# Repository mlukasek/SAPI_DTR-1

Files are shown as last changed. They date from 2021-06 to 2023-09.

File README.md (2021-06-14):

# SAPI-1 DTR-1 (Deska Testeru a RAM)

DTR-1 je modení deska pro starší 8-bitový počítač SAPI-1. Jedná se o poměrně univerzální desku, která může sloužit pro různé funkce podle nainstalovaného firmware. V současnosti firmware umožňuje:
- rychle (cca 2 min) nahrát obsah RAM disku ZRMD-1 z nebo do PC přes USB (za chodu SAPI i bez dalších desek ve sběrnici)
- nahradit desku DMR-1, resp. na ní obsažených DSM-1 a RAM-1Z (handshaking není zatím implementován)
- otestovat video RAM v AND-1Z/89
- otestovat základní RAM počítače

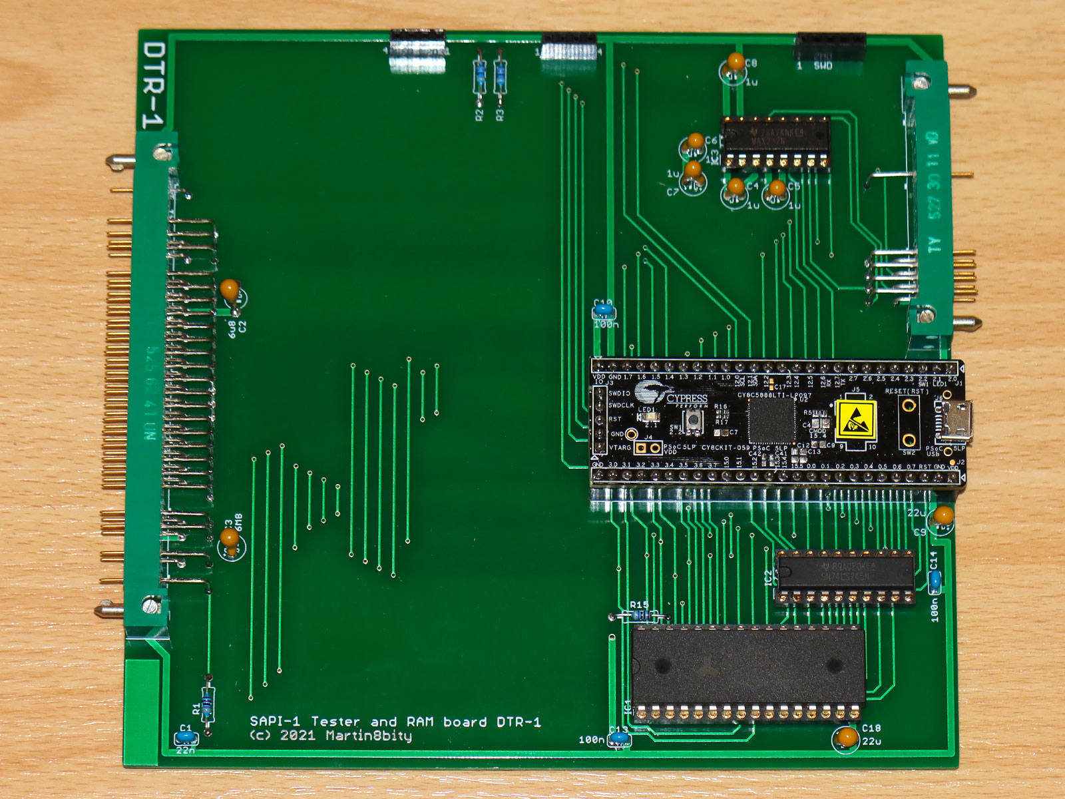
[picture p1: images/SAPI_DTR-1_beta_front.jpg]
DTR-1 PCB photo


Deska DTR-1 využívá levný Cypress (Infineon) kit CY8CKIT-059 pro různé funkce. Základem kitu je PSoC (Programmable System on a Chip) CY8C5888LTI-LP097, který kromě procesor ARM Cortex-M3 obsahuje i propojovatelnou digitální a analogovou část (něco jako CPLD). Z kitu je potřeba odpájet některé součástky, které jinak zamezují funkci některých vývodů, jakožto standardních GPIO pinů a v podstatě tak kit funguje jen jako breakout z SMD na THT technologii, aby nebylo nutné pájet SMD pouzdro.

[Schéma zapojení](https://github.com/mlukasek/SAPI_DTR-1/blob/main/HW/DTR-1_v2021-05-06_SCH.pdf)

[Seznam součástek](https://github.com/mlukasek/SAPI_DTR-1/blob/main/HW/DTR-1_v2021-05-06_BOM.csv)

[Gerber/Excellon pro výrobu DPS](https://github.com/mlukasek/SAPI_DTR-1/blob/main/HW/Gerber/DTR-1_v2021-05-06_Gerber_cor.zip)

## Odpájení některých součástek z CY8CKIT-059

Pro správnou funkci DTR-1 je potřeba z desky CY8CKIT-059 odstranit (odpájet) některé součástky. Kit je částečně analogový a na některých pinech jsou součástky, převážně kondenzátory, které by nám digitální komunikaci na sběrnici kazili, proto je potřeba asi 6 kondíků a jeden odpor z desky odpájet. Já to dělám tak, že na součástku přidám cín tak, abych byl schopen hrotem páječky z boku ohřát oba konce současně a pak součástku snadno oddělám a přebytečný cín odsaji lankem.

Konkrétně se jedná o následující součástky:
- C7, C9, C12, C13 - SAR bypass capacitors
- C41, C42 - 32 kHz crystal capacitors
- R5 nebo C4 - CMOD
- R18 - User LED resistor
- SW1 - User push button (možno ponechat, ale nesmí se stisknout, jinak připojí A2 natvrdo na GND)

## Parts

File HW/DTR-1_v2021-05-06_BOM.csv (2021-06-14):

Qty | Parts | Value | Device | Package | Description
1 | IC1 | SRAM 628128/628512 | TC551001CP | DIL32 | MEMORY SRAM
1 | IC2 | 74LS245 | 74LS245N | DIL20 | Octal BUS TRANSCEIVER 3-state
1 | IC3 | MAX232 | MAX232 | DIL16 | RS232 TRANSCEIVER
1 | Q1 | BS170 | BS170 | SOT54E | N-CHANNEL MOS FET
1 | D1 | 1N5817 | 1N5817-B | DO41-7.6 | 1.0A SCHOTTKY BARRIER RECTIFIER
1 | R1 | 47k | R-EU_0207/10 | 0207/10 | RESISTOR European symbol
3 | R2 R3 R15 | 4k7 | R-EU_0207/10 | 0207/10 | RESISTOR European symbol
1 | RN1 | DNI (optional data pull-up ~10k) | RN08 | RN-9 | RESISTOR NETWORK
1 | C1 | 22 nF | C-EU025-024X044 | C025-024X044 | CAPACITOR European symbol
3 | C10 C13 C14 | 100 nF | C-EU025-024X044 | C025-024X044 | CAPACITOR European symbol
1 | C11 | 100 nF | C-EU050-025X075 | C050-025X075 | CAPACITOR European symbol
1 | C2 | 6.8 uF | CPOL-EUE5-4 | E5-4 | POLARIZED CAPACITOR European symbol
1 | C3 | 6.8 uF | CPOL-EUE2.5-5 | E2.5-5 | POLARIZED CAPACITOR European symbol
5 | C4 C5 C6 C7 C8 | 1 uF | CPOL-EUE2.5-5 | E2.5-5 | POLARIZED CAPACITOR European symbol
2 | C9 C18 | 22 uF | CPOL-EUE2.5-5 | E2.5-5 | POLARIZED CAPACITOR European symbol
2 | JP1 JP2 | OLED power select jumper | 1x3 pin header | JP2 | JUMPER
2 | JP3 JP4 | INT/OLED jumper | 1x3 pin header | JP2 | JUMPER
1 | JP5 | optional serial module power | 1x2 pin header | 1X02 | PIN HEADER
1 | S1 | RESET | 31-XX | B3F-31XX | OMRON SWITCH
1 | SV1 | SWD | 1x5 female header + 1x5 pin header | MA05-1 | PIN HEADER
1 | SV10 | optional serial module IO | 1x4 pin header | MA04-1 | PIN HEADER
2 | SV11 SV12 | optional logic analyser connector | 1x4 pin header | MA04-1 | PIN HEADER
2 | SV2 SV3 | OLED | MA04-1 | MA04-1 | PIN HEADER
3 | SV4 SV5 SV6 | optional logic analyser connector | 1x8 pin header | MA08-1 | PIN HEADER
1 | SV7 | optional logic analyser connector | 1x10 pin header | MA10-1 | PIN HEADER
2 | SV8 SV9 | optional logic analyser connector | 1x3 pin header | MA03-1 | PIN HEADER
1 | U$1 | CY8CKIT-059 | CY8CKIT-059
2 | U$1 | CY8CKIT-059 I/O pins | 1x28 female header + 1x28 pin header
1 | U$1 | CY8CKIT-059 SWD pins | 1x5 female header + 1x5 pin header
1 | X1 | SAPI bus | SAPI_DTR-1_X1_TY_MP | TY5176211
1 | X2 | RS-232c | SAPI_DMR-1_X2_TY_MP | TY5133011

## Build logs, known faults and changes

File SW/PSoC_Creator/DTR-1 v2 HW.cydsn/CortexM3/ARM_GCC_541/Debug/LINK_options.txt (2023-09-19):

-Wl,--start-group -o "C:\\Users\\Kiwi\\Documents\\PSoC\ Creator\\DTR-1\ v2\ HW.cydsn\\CortexM3\\ARM_GCC_541\\Debug\\DTR-1\ v2\ HW.elf" ".\\CortexM3\\ARM_GCC_541\\Debug\\main.o" ".\\CortexM3\\ARM_GCC_541\\Debug\\ssd1306.o" ".\\CortexM3\\ARM_GCC_541\\Debug\\cyfitter_cfg.o" ".\\CortexM3\\ARM_GCC_541\\Debug\\cymetadata.o" ".\\CortexM3\\ARM_GCC_541\\Debug\\Cm3Start.o" ".\\CortexM3\\ARM_GCC_541\\Debug\\DTR-1\ v2\ HW.a" "C:\\Program\ Files\ (x86)\\Cypress\\PSoC\ Creator\\4.4\\PSoC\ Creator\\psoc\\content\\cycomponentlibrary\\CyComponentLibrary.cylib\\CortexM3\\ARM_GCC_541\\Debug\\CyComponentLibrary.a" -mcpu=cortex-m3 -mthumb -L "Generated_Source\\PSoC5" "-Wl,-Map,.\\CortexM3\\ARM_GCC_541\\Debug/DTR-1\ v2\ HW.map" -T "Generated_Source\\PSoC5\\cm3gcc.ld" -specs=nano.specs -Wl,--gc-sections -g -ffunction-sections -Og -ffat-lto-objects -Wl,--end-group

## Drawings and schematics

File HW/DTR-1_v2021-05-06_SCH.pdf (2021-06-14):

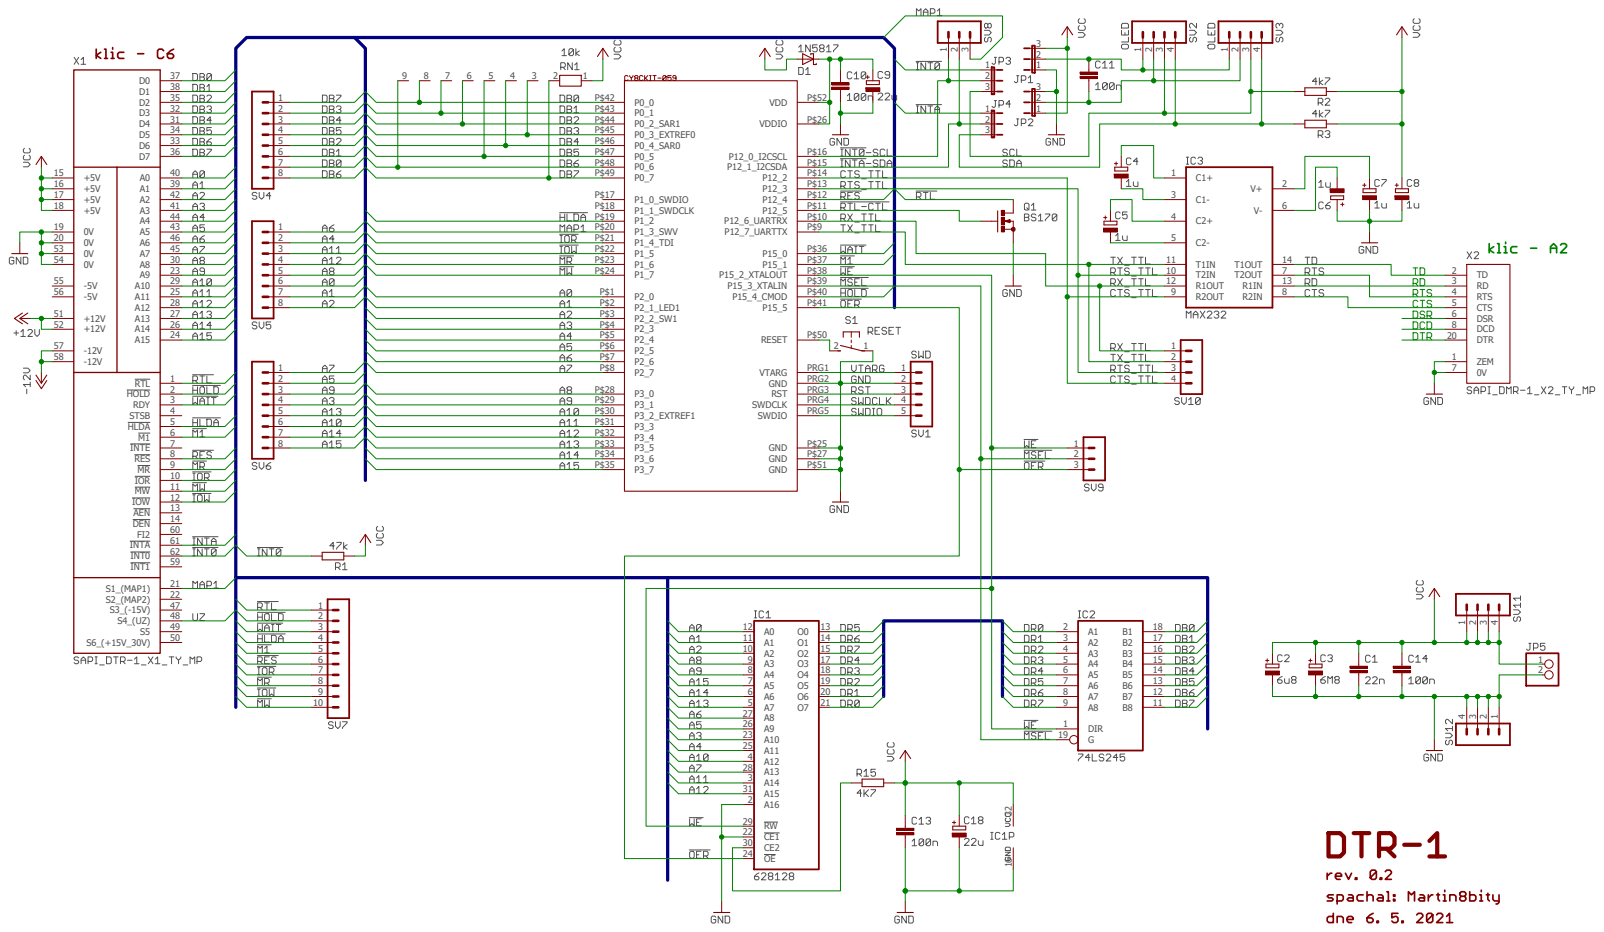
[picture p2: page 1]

+12V 52 | P2_3 P$4
-12V 57 -12V 58 | P2_4 P$5

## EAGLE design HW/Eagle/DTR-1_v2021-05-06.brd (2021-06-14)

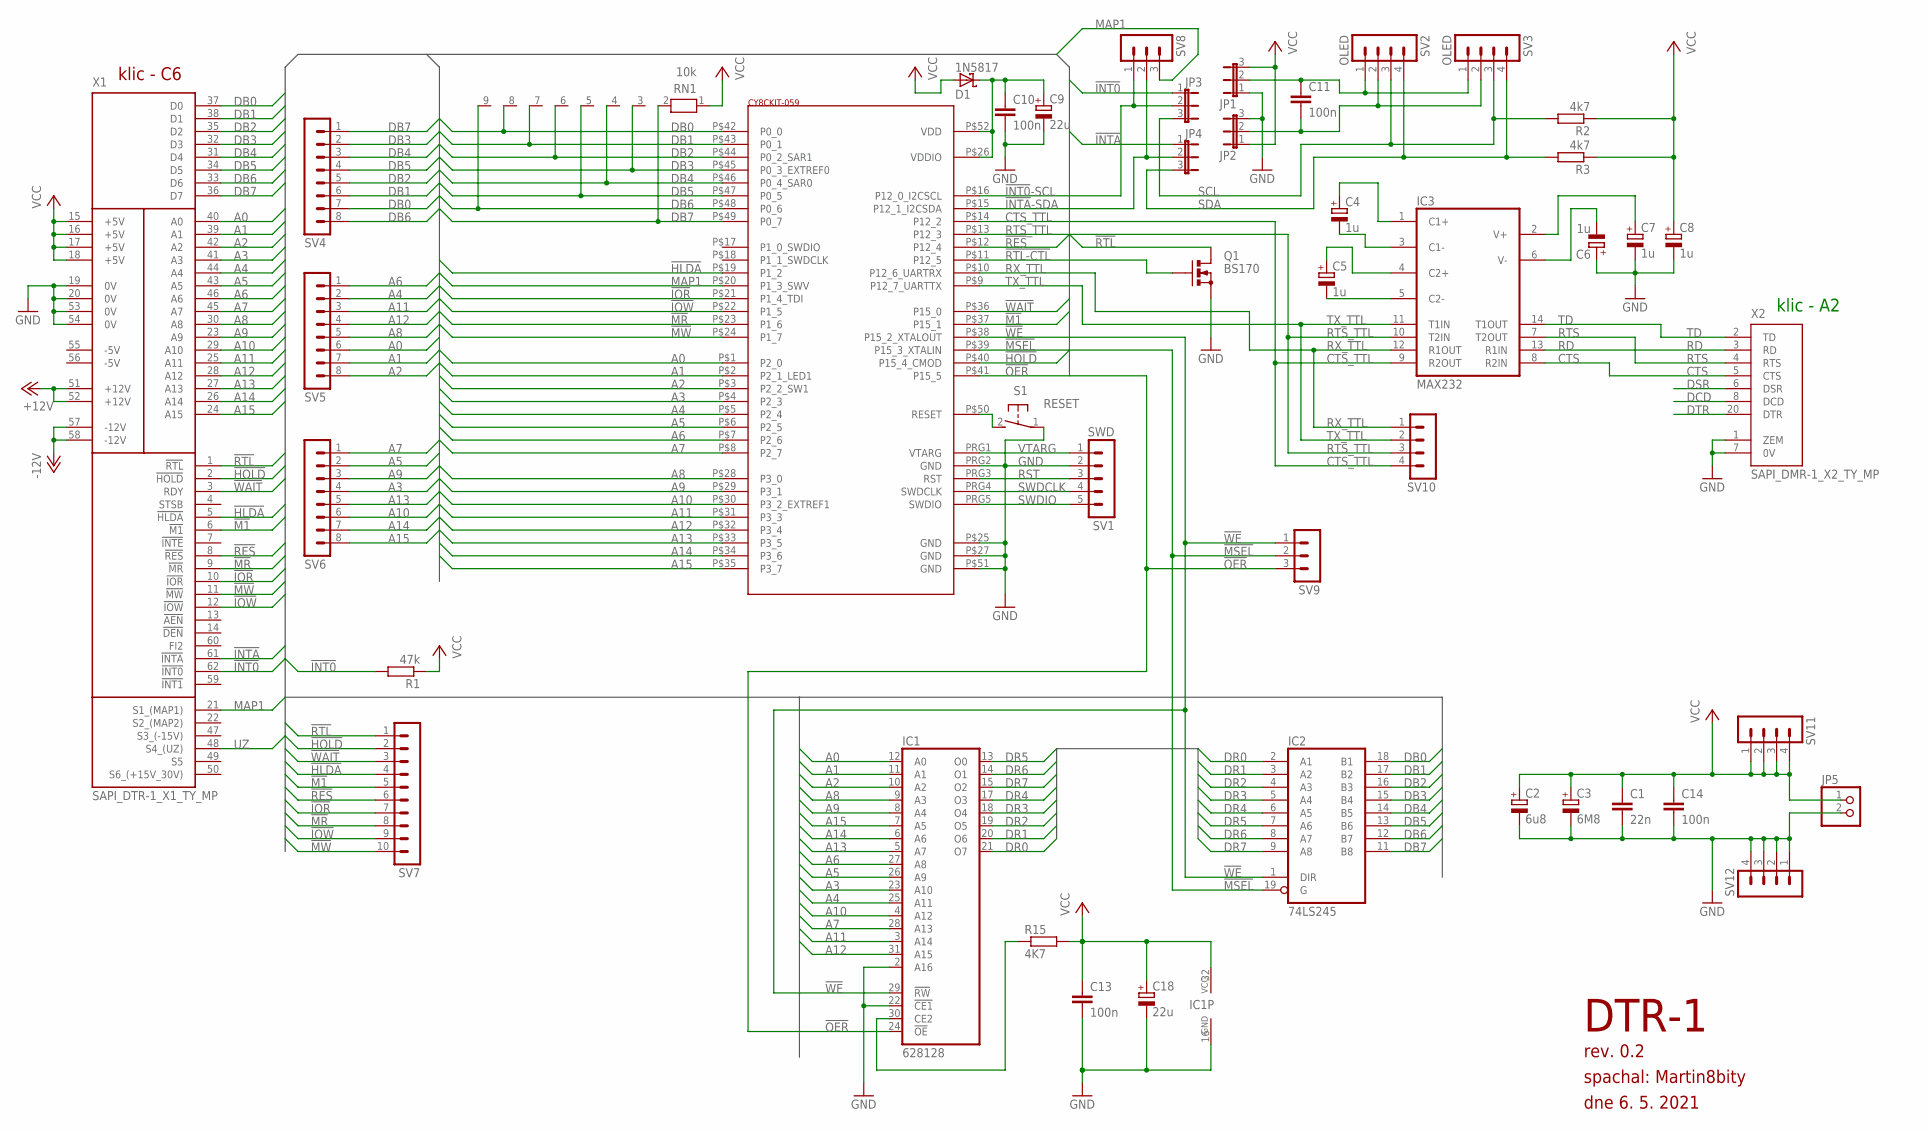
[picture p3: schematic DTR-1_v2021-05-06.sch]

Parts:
C1: 22n; C025-024X044
C2: 6u8; E5-4
C3: 6M8; E2,5-5
C4, C5, C6, C7, C8: 1u; E2,5-5
C9, C18: 22u; E2,5-5
C10, C13, C14: 100n; C025-024X044
C11: 100n; C050-025X075
D1: 1N5817; DO41-7.6
IC1: 628128; DIL32
IC2: 74LS245; DIL20
IC3: MAX232; DIL16
JP1, JP2, JP3, JP4: JP2E; JP2
JP5: PINHD-1X2; 1X02
Q1: BS170; SOT54E
R1: 47k; 0207/10
R2, R3: 4k7; 0207/10
R15: 4K7; 0207/10
RN1: 10k; RN-9
S1: RESET; B3F-31XX
SV1: SWD; MA05-1
SV2, SV3: OLED; MA04-1
SV4, SV5, SV6: MA08-1
SV7: MA10-1
SV8, SV9: MA03-1
SV10, SV11, SV12: MA04-1
U$1: CY8CKIT-059; PSOC-KIT-26
X1: SAPI_DTR-1_X1_TY_MP; TY5176211/DTR-1_X1
X2: SAPI_DMR-1_X2_TY_MP; TY5133011/DMR-1_X2

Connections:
!HLDA: SV7.4, U$1.P$19 (P1_2), X1.5 (!HLDA)
!HOLD: SV7.2, U$1.P$40 (P15_4_CMOD), X1.2 (!HOLD)
!INT0: JP3.1, R1.2, X1.62 (!INT0)
!INT0!-SCL: JP3.2, SV8.1, U$1.P$16 (P12_0_I2CSCL)
!INTA: JP4.1, X1.61 (!INTA)
!INTA!-SDA: JP4.2, SV8.2, U$1.P$15 (P12_1_I2CSDA)
!IOR: SV7.7, U$1.P$21 (P1_4_TDI), X1.10 (!IOR)
!IOW: SV7.9, U$1.P$22 (P1_5), X1.12 (!IOW)
!M1: SV7.5, U$1.P$37 (P15_1), X1.6 (!M1)
!MR: SV7.8, U$1.P$23 (P1_6), X1.9 (!MR)
!MSEL: IC2.19 (G), SV9.2, U$1.P$39 (P15_3_XTALIN)
!MW: SV7.10, U$1.P$24 (P1_7), X1.11 (!MW)
!OER: IC1.24 (!OE), SV9.3, U$1.P$41 (P15_5)
!RES: SV7.6, U$1.P$12 (P12_4), X1.8 (!RES)
!RTL: Q1.D, SV7.1, X1.1 (!RTL)
!RTL-CTL: Q1.G, U$1.P$11 (P12_5)
!WAIT: SV7.3, U$1.P$36 (P15_0), X1.3 (RDY)
!WE: IC1.29 (!RW), IC2.1 (DIR), SV9.1, U$1.P$38 (P15_2_XTALOUT)
+12V: X1.51 (+12V), X1.52 (+12V)
-12V: X1.57 (-12V), X1.58 (-12V)
A0: IC1.12 (A0), SV5.6, U$1.P$1 (P2_0), X1.40 (A0)
A1: IC1.11 (A1), SV5.7, U$1.P$2 (P2_1_LED1), X1.39 (A1)
A2: IC1.10 (A2), SV5.8, U$1.P$3 (P2_2_SW1), X1.42 (A2)
A3: IC1.23 (A10), SV6.4, U$1.P$4 (P2_3), X1.41 (A3)
A4: IC1.25 (A11), SV5.2, U$1.P$5 (P2_4), X1.44 (A4)
A5: IC1.26 (A9), SV6.2, U$1.P$6 (P2_5), X1.43 (A5)
A6: IC1.27 (A8), SV5.1, U$1.P$7 (P2_6), X1.46 (A6)
A7: IC1.28 (A13), SV6.1, U$1.P$8 (P2_7), X1.45 (A7)
A8: IC1.9 (A3), SV5.5, U$1.P$28 (P3_0), X1.30 (A8)
A9: IC1.8 (A4), SV6.3, U$1.P$29 (P3_1), X1.23 (A9)
A10: IC1.4 (A12), SV6.6, U$1.P$30 (P3_2_EXTREF1), X1.29 (A10)
A11: IC1.3 (A14), SV5.3, U$1.P$31 (P3_3), X1.25 (A11)
A12: IC1.31 (A15), SV5.4, U$1.P$32 (P3_4), X1.28 (A12)
A13: IC1.5 (A7), SV6.5, U$1.P$33 (P3_5), X1.27 (A13)
A14: IC1.6 (A6), SV6.7, U$1.P$34 (P3_6), X1.26 (A14)
A15: IC1.7 (A5), SV6.8, U$1.P$35 (P3_7), X1.24 (A15)
CTS: IC3.8 (R2IN), X2.5 (CTS)
CTS_TTL: IC3.9 (R2OUT), SV10.4, U$1.P$14 (P12_2)
DB0: IC2.18 (B1), RN1.8, SV4.7, U$1.P$42 (P0_0), X1.37 (D0)
DB1: IC2.17 (B2), RN1.7, SV4.6, U$1.P$43 (P0_1), X1.38 (D1)
DB2: IC2.16 (B3), RN1.6, SV4.5, U$1.P$44 (P0_2_SAR1), X1.35 (D2)
DB3: IC2.15 (B4), RN1.3, SV4.2, U$1.P$45 (P0_3_EXTREF0), X1.32 (D3)
DB4: IC2.14 (B5), RN1.4, SV4.3, U$1.P$46 (P0_4_SAR0), X1.31 (D4)
DB5: IC2.13 (B6), RN1.5, SV4.4, U$1.P$47 (P0_5), X1.34 (D5)
DB6: IC2.12 (B7), RN1.9, SV4.8, U$1.P$48 (P0_6), X1.33 (D6)
DB7: IC2.11 (B8), RN1.2, SV4.1, U$1.P$49 (P0_7), X1.36 (D7)
DCD: X2.8 (DCD)
DR0: IC1.21 (O7), IC2.2 (A1)
DR1: IC1.20 (O6), IC2.3 (A2)
DR2: IC1.19 (O5), IC2.4 (A3)
DR3: IC1.18 (O4), IC2.5 (A4)
DR4: IC1.17 (O3), IC2.6 (A5)
DR5: IC1.13 (O0), IC2.7 (A6)
DR6: IC1.14 (O1), IC2.8 (A7)
DR7: IC1.15 (O2), IC2.9 (A8)
DSR: X2.6 (DSR)
DTR: X2.20 (DTR)
GND: C1.2, C2.-, C3.-, C6.+, C7.-, C8.-, C9.-, C10.2, C13.2, C14.2, C18.-, IC1.2 (A16), IC1.16 (GND), IC1.22 (!CE1), IC2.10 (GND), IC3.15 (GND), JP1.1, JP2.3, JP5.2, Q1.S, S1.1, SV1.2, SV12.1, SV12.2, SV12.3, SV12.4, U$1.P$25 (GND), U$1.P$27 (GND), U$1.P$51 (GND), U$1.PRG2 (GND), X1.19 (0V), X1.20 (0V), X1.53 (0V), X1.54 (0V), X2.1 (ZEM), X2.7 (0V)
MAP1: SV8.3, U$1.P$20 (P1_3_SWV), X1.21 (S1_(MAP1))
unnamed: C9.+, C10.1, D1.C, U$1.P$26 (VDDIO), U$1.P$52 (VDD)
unnamed: S1.2 (S), U$1.P$50 (RESET)
unnamed: C11.1, JP1.2, SV2.1, SV3.1
unnamed: C6.-, IC3.6 (V-)
unnamed: C7.+, IC3.2 (V+)
unnamed: C5.-, IC3.5 (C2-)
unnamed: C5.+, IC3.4 (C2+)
unnamed: C4.-, IC3.3 (C1-)
unnamed: C4.+, IC3.1 (C1+)
unnamed: C11.2, JP2.2, SV2.2, SV3.2
unnamed: IC1.30 (CE2), R15.1
RD: IC3.13 (R1IN), X2.3 (RD)
RST: SV1.3, U$1.PRG3 (RST)
RTS: IC3.7 (T2OUT), X2.4 (RTS)
RTS_TTL: IC3.10 (T2IN), SV10.3, U$1.P$13 (P12_3)
RX_TTL: IC3.12 (R1OUT), SV10.1, U$1.P$10 (P12_6_UARTRX)
SCL: JP3.3, R2.2, SV2.3, SV3.3
SDA: JP4.3, R3.2, SV2.4, SV3.4
SWDCLK: SV1.4, U$1.PRG4 (SWDCLK)
SWDIO: SV1.5, U$1.PRG5 (SWDIO)
TD: IC3.14 (T1OUT), X2.2 (TD)
TX_TTL: IC3.11 (T1IN), SV10.2, U$1.P$9 (P12_7_UARTTX)
UZ: X1.48 (S4_(UZ))
VCC: C1.1, C2.+, C3.+, C8.+, C13.1, C14.1, C18.+, D1.A, IC1.32 (VCC), IC2.20 (VCC), IC3.16 (VCC), JP1.3, JP2.1, JP5.1, R1.1, R2.1, R3.1, R15.2, RN1.1, SV11.1, SV11.2, SV11.3, SV11.4, X1.15 (+5V), X1.16 (+5V), X1.17 (+5V), X1.18 (+5V)
VTARG: SV1.1, U$1.PRG1 (VTARG)

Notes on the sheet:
DTR-1
spachal: Martin8bity
dne 6. 5. 2021
klic - C6
klic - A2
rev. 0.2

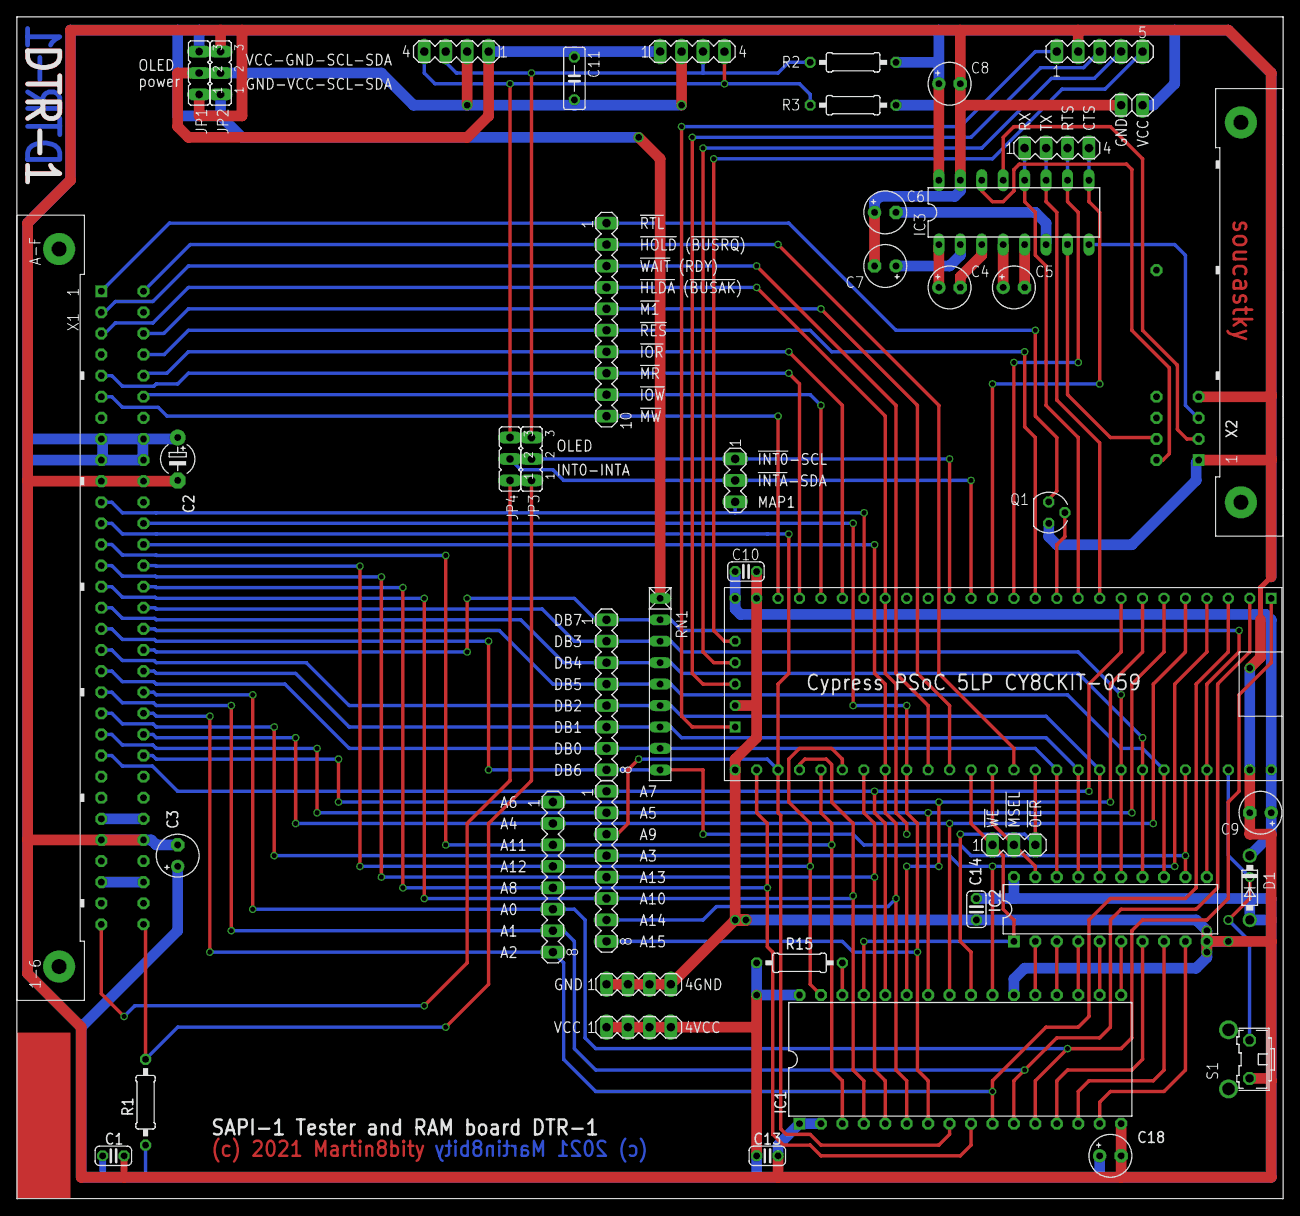
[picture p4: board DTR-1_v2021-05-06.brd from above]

Board: 2 copper layers, 150.0 x 140.0 mm, 45 parts (0 on the bottom side), 80 nets.

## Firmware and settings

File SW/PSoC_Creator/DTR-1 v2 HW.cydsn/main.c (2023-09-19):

/* ========================================
 *
 * Copyright Martin Lukasek (c) 2021
 * All Rights Reserved
 * UNPUBLISHED, LICENSED SOFTWARE.
 *
 * CONFIDENTIAL AND PROPRIETARY INFORMATION
 * WHICH IS THE PROPERTY OF Martin Lukasek.
 *
 * ========================================
*/
#include <stdio.h>
#include <stdarg.h>
#include "project.h"
#include "ssd1306.h"

#define DISPLAY_ADDRESS 0x3C // 011110+SA0+RW - 0x3C or 0x3D

int noUART = 1;
uint16 extaddr = 0;
uint32 cntTime = 0;
uint32 cntLines = 0;
uint32 cntErrs = 0;
uint8 waitForBus = 1;

int noOLED = 1;

struct PortData
{
    uint8 port;
    uint8 data;
};

struct PortData intQueue[256];
volatile uint8 intCnt = 0;
volatile uint8 rdCnt = 0;

struct InstData
{
    uint16 addr;
    uint8 data;
};

struct InstData instQueue[256];
volatile uint8 instCnt = 0;
volatile uint8 instRdCnt = 0;

CY_ISR( UART_OUT_RCM_Handler )
{
    intQueue[intCnt].port = 0x10;
    intQueue[intCnt].data = RCM_Read();
    intCnt++;
}

CY_ISR( UART_OUT_RCU_Handler )
{
    intQueue[intCnt].port = 0x11;
    intQueue[intCnt].data = RCU_Read();
    intCnt++;
}

CY_ISR( UART_OUT_ROD_Handler )
{
    intQueue[intCnt].port = 0x12;
    intQueue[intCnt].data = ROD_Read();
    intCnt++;
}

CY_ISR( UART_OUT_RST_Handler )
{
    intQueue[intCnt].port = 0x13;
    intQueue[intCnt].data = RST_Read();
    intCnt++;
}

CY_ISR( UART_IN_RRD_Handler )
{
    RSU_Write( RSU_Read() & 0x7F );
}

CY_ISR( M1_Int_Handler )
{
    nWAIT_Write(0);
    //instQueue[instCnt].addr = (AddrH_Read()<<8) + AddrL_Read();
    //instQueue[instCnt].data = Dta_Read();
    //CyDelay(2);
    instQueue[instCnt].addr = (ADH_Reg_Read()<<8) + ADL_Reg_Read();
    instQueue[instCnt].data = DT_Reg_Read();
    instCnt++;
}

#define BS170
void SAPI_Reset() {
#ifdef BS170
    RTL_Write(1);
    CyDelay(6);
    RTL_Write(0);
#else
    RTL_Write(0);
    CyDelay(6);
    RTL_Write(1);
#endif
    //CyDelay(1);
}

int USBUART_printf(const char *format, ...)
{
    if(noUART)
        return -1;

    char tmpstr[128];
    int ret;
    
    va_list args;
    va_start(args, format);

    ret=vsprintf(tmpstr, format, args);
    while(!USBUART_CDCIsReady());
    USBUART_PutString(tmpstr);
    
    va_end(args);
    
    return ret;
}    

int UART_printf(const char *format, ...)
{
    char tmpstr[128];
    int ret;
    
    va_list args;
    va_start(args, format);

    ret=vsprintf(tmpstr, format, args);
    // while(!UART_CDCIsReady());
    UART_PutString(tmpstr);
    
    va_end(args);
    
    return ret;
}    

/*
void TermPutString(char * str) {
    if(noUART)
        return;
    if(strlen(str)>50) // aaa - correct later, but large string would block
        return;
    uint32 timeout = Millis_ReadCounter();
    if (0u != USBUART_GetConfiguration()) {    
        while (0u == USBUART_CDCIsReady())
        {
            if (Millis_ReadCounter()-timeout > 100) {
                return; // prevent getting stuck
            }
        }    
        USBUART_PutString(str);
    }
    timeout = Millis_ReadCounter();
    while((!USBUART_CDCIsReady()) && (Millis_ReadCounter()-timeout<100)){     // Wait for Tx to finish, timeout after 100 ms
        CyDelay(1);
    }
}    

void TermPutChar(char ch) {
    if(noUART)
        return;
    // USBUART_PutChar(ch);
    uint32 timeout = Millis_ReadCounter();
    if (0u != USBUART_GetConfiguration()) {    
        while (0u == USBUART_CDCIsReady())
        {
            if (Millis_ReadCounter()-timeout > 100) {
                return; // prevent getting stuck
            }
        }    
        USBUART_PutChar(ch);
    }
    timeout = Millis_ReadCounter();
    while((!USBUART_CDCIsReady()) && (Millis_ReadCounter()-timeout<100)){     // Wait for Tx to finish, timeout after 100 ms
        CyDelay(1);
    }
}    
*/

uint8 Get_SAPI_Bus() {
    // USBUART_printf("BUSAK = %d\r\n", BUSAK_Read());
    if(waitForBus==0)
        return 1;
    BUSRQ_Write(0);
    USBUART_printf("Waiting BUSAK ... ");
    while(BUSAK_Read()!=0) {
        USBUART_printf(".");
        CyDelay(10);
    }
    if(BUSAK_Read()==0) {
        USBUART_printf("OK\r\n");
        return 1;
    } else {
        USBUART_printf("FAILED\r\n");
        return 0;
    }
}

uint8 Get_SAPI_Bus_Silent() {
    // USBUART_printf("BUSAK = %d\r\n", BUSAK_Read());
    if(waitForBus==0)
        return 1;
    BUSRQ_Write(0);
    //USBUART_printf("Waiting BUSAK ... ");
    while(BUSAK_Read()!=0) {
        //USBUART_printf(".");
        CyDelay(1);
    }
    if(BUSAK_Read()==0) {
        //USBUART_printf("OK\r\n");
        return 1;
    } else {
        //USBUART_printf("FAILED\r\n");
        return 0;
    }
}

uint8 Release_SAPI_Bus() {
    if(waitForBus==0)
        return 1;
    BUSRQ_Write(1);
    USBUART_printf("Waiting BUS release ... ");
    while(BUSAK_Read()!=1) {
        USBUART_printf(".");
        CyDelay(10);
    }
    if(BUSAK_Read()==1) {
        USBUART_printf("OK\r\n");
        return 1;
    } else {
        USBUART_printf("FAILED\r\n");
        return 0;
    }
}

uint8 Release_SAPI_Bus_Silent() {
    if(waitForBus==0)
        return 1;
    BUSRQ_Write(1);
    //USBUART_printf("Waiting BUS release ... ");
    while(BUSAK_Read()!=1) {
        //USBUART_printf(".");
        CyDelay(1);
    }
    if(BUSAK_Read()==1) {
        //USBUART_printf("OK\r\n");
        return 1;
    } else {
        //USBUART_printf("FAILED\r\n");
        return 0;
    }
}

void DumpMem(uint16 addr);

void RAM_check() {
    uint32 testfrom = 0x0000;
    uint32 testlen = 0x10000;
    uint8 r;
    uint8 s;
    int err=0;
    
    if(!Get_SAPI_Bus()) {
        return;
    }

    AddrL_Write(0);
    AddrL_SetDriveMode(PIN_DM_STRONG);
    AddrH_Write(0);
    AddrH_SetDriveMode(PIN_DM_STRONG);
    
    // SRAM under my control DATAOUT CTL OER WE MSEL
    SRAM_Ctl_Write(0b01111);
    
    USBUART_printf("filling RAM with patttern\r\n");
    for(uint32 a=testfrom; a<testfrom+testlen; a=a+2) {
        AddrH_Write((a>>8)&0xFF);
        AddrL_Write(a&0xFF);
        BusDta_Write((a>>8)&0xFF);
        // DATAOUT + WE + MSEL
        SRAM_Ctl_Write(0b11100);
        CyDelayUs(1);
        SRAM_Ctl_Write(0b01111);
        CyDelayUs(1);
        AddrL_Write((a&0xFF)+1);
        BusDta_Write(a);
        SRAM_Ctl_Write(0b11100);
        CyDelayUs(1);
        SRAM_Ctl_Write(0b01111);
        CyDelayUs(1);
    }
    USBUART_printf("verifying RAM\r\n");

    // OER + MSEL = furt data ze SRAM na sbernici
    SRAM_Ctl_Write(0b01010);

    for(uint32 a=testfrom; a<testlen; a++) {
        AddrH_Write((a>>8)&0xFF);
        AddrL_Write(a&0xFF);
        CyDelayUs(2);
        r=Dta_Read();
        CyDelayUs(1);
        //USBUART_printf("%02X", r);
        //if((a&0x1F)==0x1F)
        //    USBUART_printf("\r\n");
        if(a&1) {
            s=(a&0xFF)-1;
        } else {
            s=(a>>8)&0xFF;
        }
        if(r!=s) {
            USBUART_printf("Error at %04X, expected %02X, but found %02X\r\n", a, s, r);
            err++;
            DumpMem(a & 0xFF00);
            if(!Get_SAPI_Bus()) {
                return;
            }
            AddrL_SetDriveMode(PIN_DM_STRONG);
            AddrH_SetDriveMode(PIN_DM_STRONG);
            SRAM_Ctl_Write(0b01010);
        }
    }

    // SRAM under my control DATAOUT CTL OER WE MSEL
    SRAM_Ctl_Write(0b01111);
    
    USBUART_printf("filling RAM with inverted patttern\r\n");
    for(uint32 a=testfrom; a<testfrom+testlen; a=a+2) {
        AddrH_Write((a>>8)&0xFF);
        AddrL_Write(a&0xFF);
        BusDta_Write(~((a>>8)&0xFF));
        // DATAOUT + WE + MSEL
        SRAM_Ctl_Write(0b11100);
        CyDelayUs(1);
        SRAM_Ctl_Write(0b01111);
        CyDelayUs(1);
        AddrL_Write((a&0xFF)+1);
        BusDta_Write(~a);
        SRAM_Ctl_Write(0b11100);
        CyDelayUs(1);
        SRAM_Ctl_Write(0b01111);
        CyDelayUs(1);
    }
    USBUART_printf("verifying RAM\r\n");

    // OER + MSEL = furt data ze SRAM na sbernici
    SRAM_Ctl_Write(0b01010);

    for(uint32 a=testfrom; a<testlen; a++) {
        AddrH_Write((a>>8)&0xFF);
        AddrL_Write(a&0xFF);
        CyDelayUs(1);
        r=Dta_Read();
        CyDelayUs(1);
        //USBUART_printf("%02X", r);
        //if((a&0x1F)==0x1F)
        //    USBUART_printf("\r\n");
        if(a&1) {
            s=~((a&0xFF)-1);
        } else {
            s=~((a>>8)&0xFF);
        }
        if(r!=s) {
            USBUART_printf("Error at %04X, expected %02X, but found %02X\r\n", a, s, r);
            err++;
        }
    }

    // relase SRAM to SAPI - CTL OER WE MSEL
    SRAM_Ctl_Write(0b00111);
    
    AddrL_Write(0);
    AddrL_SetDriveMode(PIN_DM_DIG_HIZ);
    AddrH_Write(0);
    AddrH_SetDriveMode(PIN_DM_DIG_HIZ);
    //Dta_Write(0xFF);
    //Dta_SetDriveMode(PIN_DM_RES_UP);
    
    if(err) {
        USBUART_printf("%d errors found :-(\r\n", err);
    } else {
        USBUART_printf("No errors found :-)\r\n");
    }
    Release_SAPI_Bus();

    USBUART_printf("Data has been corrupted by memory test, performing SAPI reset.\r\n");
    SAPI_Reset();
}

void DumpMem(uint16 addr) {
    uint8 r;

    if(!Get_SAPI_Bus()) {
        return;
    }

    // SRAM under my control DATAOUT CTL OER WE MSEL
    SRAM_Ctl_Write(0b01111);
    
    AddrL_Write(0);
    AddrL_SetDriveMode(PIN_DM_STRONG);
    AddrH_Write(0);
    AddrH_SetDriveMode(PIN_DM_STRONG);
    
    // USBUART_printf("reading RAM\r\n");

    // OER + MSEL = furt SRAM data na sbernici
    SRAM_Ctl_Write(0b01010);

    for(uint32 a=addr; a<addr+256; a++) {
        AddrH_Write((a>>8)&0xFF);
        AddrL_Write(a&0xFF);
        CyDelayUs(5);
        r=Dta_Read();
        CyDelayUs(5);
        if((a&0x1F)==0x00)
            USBUART_printf("%04X: ", a);
        USBUART_printf("%02X", r);
        if((a&0x1F)==0x1F)
            USBUART_printf("\r\n");
    }

    // relase SRAM to SAPI - DATAOUT CTL OER WE MSEL
    SRAM_Ctl_Write(0b00111);
    
    AddrL_Write(0);
    AddrL_SetDriveMode(PIN_DM_DIG_HIZ);
    AddrH_Write(0);
    AddrH_SetDriveMode(PIN_DM_DIG_HIZ);
    
    Release_SAPI_Bus();
}

void TestVideo() {
    uint8 r;
    uint16 err=0;

    if(!Get_SAPI_Bus()) {
        return;
    }

    AddrL_Write(0);
    AddrL_SetDriveMode(PIN_DM_STRONG);
    AddrH_Write(0);
    AddrH_SetDriveMode(PIN_DM_STRONG);
    MW_Write(1);
    MW_SetDriveMode(PIN_DM_STRONG);
    MR_Write(1);
    MR_SetDriveMode(PIN_DM_STRONG);
    
    USBUART_printf("Checking AND-1Z video RAM 0xF800-0xFCFF\r\n");

    /*
    for(uint32 a=0xF000; a<0xF000+256; a++) {
        AddrH_Write((a>>8)&0xFF);
        AddrL_Write(a&0xFF);
        MR_Write(0);
        CyDelayUs(5);
        r=Dta_Read();
        CyDelayUs(5);
        if((a&0x1F)==0x00)
            USBUART_printf("%04X: ", a);
        USBUART_printf("%02X", r);
        if((a&0x1F)==0x1F)
            USBUART_printf("\r\n");
    }
    */
    for(uint32 a=0xF800; a<0xF800+1280; a++) {
        AddrH_Write((a>>8)&0xFF);
        AddrL_Write(a&0xFF);
        // read current value
        MR_Write(0);
        CyDelayUs(5);
        r=Dta_Read();
        MR_Write(1);
        CyDelayUs(5);
        
        // write 0xA5
        BusDta_Write(0xA5);
        // BusData to bus (DATAOUT CTL OER WE MSEL)
        SRAM_Ctl_Write(0b10111);
        MW_Write(0);
        CyDelayUs(5);
        MW_Write(1);
        SRAM_Ctl_Write(0b00111);
        CyDelayUs(5);
        // check 0xA5
        MR_Write(0);
        CyDelayUs(5);
        if(Dta_Read()!=0xA5) {
            USBUART_printf("Error at %04X, expected %02X, found %02X\r\n", a, 0xA5, Dta_Read());
            err++;
        }
        MR_Write(1);
        CyDelayUs(5);
        
        // write 0x5A
        BusDta_Write(0x5A);
        // BusData to bus (DATAOUT CTL OER WE MSEL)
        SRAM_Ctl_Write(0b10111);
        MW_Write(0);
        CyDelayUs(5);
        MW_Write(1);
        SRAM_Ctl_Write(0b00111);
        CyDelayUs(5);
        // check 0x5A
        MR_Write(0);
        CyDelayUs(5);
        if(Dta_Read()!=0x5A) {
            USBUART_printf("Error at %04X, expected %02X, found %02X\r\n", a, 0x5A, Dta_Read());
            err++;
        }
        MR_Write(1);
        CyDelayUs(5);

        CyDelay(1);
        
        // write back original value
        BusDta_Write(r);
        // BusData to bus (DATAOUT CTL OER WE MSEL)
        SRAM_Ctl_Write(0b10111);
        MW_Write(0);
        CyDelayUs(5);
        MW_Write(1);
        SRAM_Ctl_Write(0b00111);
        CyDelayUs(5);
    }
    
    SRAM_Ctl_Write(0b00111);
    AddrL_Write(0);
    AddrL_SetDriveMode(PIN_DM_DIG_HIZ);
    AddrH_Write(0);
    AddrH_SetDriveMode(PIN_DM_DIG_HIZ);
    MR_Write(1);
    MR_SetDriveMode(PIN_DM_DIG_HIZ);
    MW_Write(1);
    MW_SetDriveMode(PIN_DM_DIG_HIZ);
    
    if(err==0) {
        USBUART_printf("No erros found :-)\r\n", err);
    } else {
        USBUART_printf("Found %d errors :-(\r\n", err);
    }
    
    Release_SAPI_Bus();
}

void WriteIO8(uint8 port, uint8 value) {
    // do not call this without reserving bus first
    AddrL_Write(port);
    BusDta_Write(value);
    SRAM_Ctl_Write(0b10111);
    //CyDelayUs(5);
    IOW_Write(0);
    CyDelayUs(4);
    IOW_Write(1);
    SRAM_Ctl_Write(0b00111);
    //CyDelayUs(5);
}
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
int main(void)
{
    CyGlobalIntEnable; /* Enable global interrupts. */
    
    RCM_Int_StartEx( UART_OUT_RCM_Handler );
    RCU_Int_StartEx( UART_OUT_RCU_Handler );
    ROD_Int_StartEx( UART_OUT_ROD_Handler );
    RST_Int_StartEx( UART_OUT_RST_Handler );
    RRD_Int_StartEx( UART_IN_RRD_Handler );
    M1_Int_StartEx( M1_Int_Handler );
    M1_Int_Disable();
    
    /* Place your initialization/startup code here (e.g. MyInst_Start()) */

    //AddrL_Write(0);
    
    Millis_Start();
    I2COLED_Start();
    UART_Start();
    // uint8 oledStatus = I2COLED_MasterStatus();
    // UART_printf("I2COLED_MasterStatus() = %02X\r\n", oledStatus);
    if(I2COLED_MasterSendStart(DISPLAY_ADDRESS, 0)) {
        I2COLED_MasterSendStop();
        // UART_printf("OLED display NOT present on the bus\r\n");
        noOLED = 1;
    } else {
        I2COLED_MasterSendStop();
        // UART_printf("OLED display present in the bus\r\n");
        //uint8 iniseq[] = {0xA8, 0x3F, 0xD3, 0x00, 0x40, 0xA0, 0xC0, 0xDA, 0x02, 0x81, 0x7F, 0xA4, 0xA6, 0xD5, 0x80, 0x8D, 0x14, 0xAF};
        // I2COLED_MasterClearStatus();
        //I2COLED_MasterWriteBuf(DISPLAY_ADDRESS, &iniseq, 18, 0 ); //I2C_MODE_COMPLETE_XFER
        //CyDelay(1000);
        noOLED = 0;
        display_init(DISPLAY_ADDRESS);
        display_clear();    
        gfx_setTextSize(2);
        gfx_setTextColor(WHITE);
        gfx_setTextBg(BLACK);
        gfx_setCursor(0,0);
        gfx_println("SAPI DTR-1");
        gfx_println("8bity.cz");
        gfx_println("2021042501");
        display_update();
    }

    cntTime = Millis_ReadCounter();
    
    USBUART_Start(0, USBUART_5V_OPERATION); //!!NOTE!! Make sure this matches your board voltage!
    uint32 timeout = Millis_ReadCounter();
    while((!USBUART_GetConfiguration()) && (Millis_ReadCounter()-timeout<2000)){
        CyDelay(1);
    }
    if(Millis_ReadCounter()-timeout<2000) {
        USBUART_CDC_Init();
        noUART = 0;
        /*gfx_setCursor(0,32);
        gfx_print("Ready     ");
        gfx_print("          ");
        display_update();*/
    } else {
        noUART = 1;
        /*gfx_setCursor(0,32);
        gfx_print("No USBUART");
        gfx_print("          ");
        display_update();*/
    }
    USBUART_printf("");
    USBUART_printf("\r\nSAPI-1 DTR-1 board based on CY8CKIT-059 rev.231709");
    USBUART_printf("  (c) 2021-23 martin@8bity.cz\r\n\r\n");

    //USBUART_printf("CTS = %d\r\n", CTS_Read());
    if( CTS_Read()==1 ) {
        RSM_Write(0x20);
        USBUART_printf("Console set to AND-1Z and Consul 262.3/259.11\r\n");
    } else {
        RSM_Write(0x00);
        USBUART_printf("Console set to RS-232c RTS/CTS flow control\r\n");
        UART_printf("\r\nHello to UART RS-232c console\r\n");
    }
    
    if(noOLED) {
        USBUART_printf("OLED display not found.\r\n");
    } else {
        USBUART_printf("OLED display detected.\r\n");
    }
    instCnt=0;
    instRdCnt=0;
    nWAIT_Write(1);
    //CyDelay(2);
    SAPI_Reset();
    int getInst=0;
    int tron=0;
    M1_Int_ClearPending();
    // M1_Int_Enable();
    
    
    char cmdline[128];
    uint8 inbuf[64];
    cmdline[0] = 0;
    char ch;
    // char tmpstr[256];
    int len;
    uint8 noPrompt = 0;

    USBUART_printf("DTR>");
    for(;;)
    {
        // process DSM-1 Register interrupt queue
        if(rdCnt!=intCnt) {
            // USBUART_printf("\r\nProcessing %d OUT interrupts:\r\n", intCnt-rdCnt);
            while(rdCnt!=intCnt) {
                // USBUART_printf("OUT: port=%d data=%d\r\n", intQueue[rdCnt].port, intQueue[rdCnt].data);
                // uint8 intStatus = CyEnterCriticalSection();
                switch(intQueue[rdCnt].port) {
                    case 0x10: // RCM
                        break;
                    case 0x11: // RCU
                        break;
                    case 0x12: // ROD
                        UART_PutChar(intQueue[rdCnt].data);
                        break;
                    case 0x13: // RST
                        break;
                }
                rdCnt++;
                //CyExitCriticalSection(intStatus);
            }
        }

        // process Instruction (M1) interrupt queue
        if(instRdCnt!=instCnt) {
            if(getInst>0) {
                USBUART_printf("TR %04X:%02X\r\n", instQueue[instRdCnt].addr, instQueue[instRdCnt].data);
                getInst--;
                if(getInst==0) {
                    M1_Int_Disable();
                    M1_Int_ClearPending();
                    tron=0;
                    USBUART_printf("DTR>");
                    noPrompt = 0;
                }
            }
            //USBUART_printf("%02X ", instQueue[instRdCnt].data);
            instRdCnt++;
            if(instRdCnt==instCnt)
                nWAIT_Write(1);
        }
        
        if(UART_GetRxBufferSize()>0) {
            RRD_Write( UART_GetByte() & 0x00FF );
            RSU_Write( RSU_Read() | 0x80 );
        }
        // process USBUART - command line
        if(USBUART_DataIsReady()>0) {
            int dtalen = USBUART_GetAll(inbuf);
            for(int i=0; i<dtalen; i++) {
                ch = inbuf[i];
                switch(ch) {
                  case 0x08: // backpasce
                    len = strlen(cmdline);
                    if(len>0) {
                        cmdline[len-1] = 0;
                        USBUART_printf("\b \b");            
                    }
                    break;
                  case 0x0D: // Enter
                    // USBUART_printf("\r\nWill process: [%s]\r\n", cmdline);
                    USBUART_printf("\r\n");
                    int cmdprocessed = 0;
                    if(cmdline[0]==':' && !cmdprocessed) {
                        ProcessHEX(cmdline);
                        cmdprocessed = 1;
                        noPrompt = 0;
                    }
                    if((strncmp(cmdline, "help", 4)==0 || strcmp(cmdline, "?")==0 || strcmp(cmdline, "h")==0) && !cmdprocessed) {
                        ShowHelp();
                        cmdprocessed = 1;
                        noPrompt = 0;
                    }
                    if(strcmp(cmdline, "zdump")==0 && !cmdprocessed) {
                        DumpZRMD();
                        cmdprocessed = 1;
                        noPrompt = 0;
                    }
                    if(strcmp(cmdline, "dumpu")==0 && !cmdprocessed) {
                        // DumpZRMD_UART();
                        cmdprocessed = 1;
                        noPrompt = 0;
                    }
                    if(strcmp(cmdline, "dm")==0 && !cmdprocessed) {
                        DumpMem(0xF000);
                        cmdprocessed = 1;
                        noPrompt = 0;
                    }
                    if(strcmp(cmdline, "vidtest")==0 && !cmdprocessed) {
                        TestVideo();
                        cmdprocessed = 1;
                        noPrompt = 0;
                    }
                    if(strcmp(cmdline, "hex")==0 && !cmdprocessed) {
                        HEX_read();
                        cmdprocessed = 1;
                        noPrompt = 0;
                    }
                    if(strcmp(cmdline, "memtest")==0 && !cmdprocessed) {
                        RAM_check();
                        cmdprocessed = 1;
                        noPrompt = 0;
                    }
                    if(strcmp(cmdline, "reset")==0 && !cmdprocessed) {
                        SAPI_Reset();
                        USBUART_printf("SAPI reset.\r\n", cmdline);
                        cmdprocessed = 1;
                        noPrompt = 0;
                    }
                    if(strcmp(cmdline, "rescnt")==0 && !cmdprocessed) {
                        cntTime = Millis_ReadCounter();
                        cntLines = 0;
                        cntErrs = 0;
                        USBUART_printf("Counter reset.\r\n", cmdline);
                        cmdprocessed = 1;
                        noPrompt = 0;
                    }
                    if(strcmp(cmdline, "cnt")==0 && !cmdprocessed) {
                        USBUART_printf("Elapsed time = %d ms, %d lines processed, %d errors\r\n", Millis_ReadCounter()-cntTime, cntLines, cntErrs);
                        cmdprocessed = 1;
                        noPrompt = 0;
                    }
                    if(strcmp(cmdline, "tron")==0 && !cmdprocessed) {
                        if(!tron) {
                            instCnt=0;
                            instRdCnt=0;
                            M1_Int_ClearPending();
                            M1_Int_Enable();
                            tron=1;
                        }
                        getInst=16;
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

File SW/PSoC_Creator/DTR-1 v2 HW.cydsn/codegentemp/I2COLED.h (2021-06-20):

/*******************************************************************************
* File Name: I2COLED.h
* Version 3.50
*
* Description:
*  This file provides constants and parameter values for the I2C component.

*
********************************************************************************
* Copyright 2008-2015, Cypress Semiconductor Corporation. All rights reserved.
* You may use this file only in accordance with the license, terms, conditions,
* disclaimers, and limitations in the end user license agreement accompanying
* the software package with which this file was provided.
*******************************************************************************/

#if !defined(CY_I2C_I2COLED_H)
#define CY_I2C_I2COLED_H

#include "cyfitter.h"
#include "cytypes.h"
#include "CyLib.h"

/* Check if required defines such as CY_PSOC5LP are available in cy_boot */
#if !defined (CY_PSOC5LP)
    #error Component I2C_v3_50 requires cy_boot v3.10 or later
#endif /* (CY_PSOC5LP) */


/***************************************
*   Conditional Compilation Parameters
****************************************/

#define I2COLED_IMPLEMENTATION     (1u)
#define I2COLED_MODE               (2u)
#define I2COLED_ENABLE_WAKEUP      (0u)
#define I2COLED_ADDR_DECODE        (1u)
#define I2COLED_UDB_INTRN_CLOCK    (0u)


/* I2C implementation enum */
#define I2COLED_UDB    (0x00u)
#define I2COLED_FF     (0x01u)

#define I2COLED_FF_IMPLEMENTED     (I2COLED_FF  == I2COLED_IMPLEMENTATION)
#define I2COLED_UDB_IMPLEMENTED    (I2COLED_UDB == I2COLED_IMPLEMENTATION)

#define I2COLED_UDB_INTRN_CLOCK_ENABLED    (I2COLED_UDB_IMPLEMENTED && \
                                                     (0u != I2COLED_UDB_INTRN_CLOCK))
/* I2C modes enum */
#define I2COLED_MODE_SLAVE                 (0x01u)
#define I2COLED_MODE_MASTER                (0x02u)
#define I2COLED_MODE_MULTI_MASTER          (0x06u)
#define I2COLED_MODE_MULTI_MASTER_SLAVE    (0x07u)
#define I2COLED_MODE_MULTI_MASTER_MASK     (0x04u)

#define I2COLED_MODE_SLAVE_ENABLED         (0u != (I2COLED_MODE_SLAVE  & I2COLED_MODE))
#define I2COLED_MODE_MASTER_ENABLED        (0u != (I2COLED_MODE_MASTER & I2COLED_MODE))
#define I2COLED_MODE_MULTI_MASTER_ENABLED  (0u != (I2COLED_MODE_MULTI_MASTER_MASK & \
                                                            I2COLED_MODE))
#define I2COLED_MODE_MULTI_MASTER_SLAVE_ENABLED    (I2COLED_MODE_MULTI_MASTER_SLAVE == \
                                                             I2COLED_MODE)

/* Address detection enum */
#define I2COLED_SW_DECODE      (0x00u)
#define I2COLED_HW_DECODE      (0x01u)

#define I2COLED_SW_ADRR_DECODE             (I2COLED_SW_DECODE == I2COLED_ADDR_DECODE)
#define I2COLED_HW_ADRR_DECODE             (I2COLED_HW_DECODE == I2COLED_ADDR_DECODE)

/* Wakeup enabled */
#define I2COLED_WAKEUP_ENABLED             (0u != I2COLED_ENABLE_WAKEUP)

/* Adds bootloader APIs to component */
#define I2COLED_BOOTLOADER_INTERFACE_ENABLED   (I2COLED_MODE_SLAVE_ENABLED && \
                                                            ((CYDEV_BOOTLOADER_IO_COMP == CyBtldr_I2COLED) || \
                                                             (CYDEV_BOOTLOADER_IO_COMP == CyBtldr_Custom_Interface)))

/* Timeout functionality */
#define I2COLED_TIMEOUT_ENABLE             (0u)
#define I2COLED_TIMEOUT_SCL_TMOUT_ENABLE   (0u)
#define I2COLED_TIMEOUT_SDA_TMOUT_ENABLE   (0u)
#define I2COLED_TIMEOUT_PRESCALER_ENABLE   (0u)
#define I2COLED_TIMEOUT_IMPLEMENTATION     (0u)

/* Convert to boolean */
#define I2COLED_TIMEOUT_ENABLED            (0u != I2COLED_TIMEOUT_ENABLE)
#define I2COLED_TIMEOUT_SCL_TMOUT_ENABLED  (0u != I2COLED_TIMEOUT_SCL_TMOUT_ENABLE)
#define I2COLED_TIMEOUT_SDA_TMOUT_ENABLED  (0u != I2COLED_TIMEOUT_SDA_TMOUT_ENABLE)
#define I2COLED_TIMEOUT_PRESCALER_ENABLED  (0u != I2COLED_TIMEOUT_PRESCALER_ENABLE)

/* Timeout implementation enum. */
#define I2COLED_TIMEOUT_UDB    (0x00u)
#define I2COLED_TIMEOUT_FF     (0x01u)

#define I2COLED_TIMEOUT_FF_IMPLEMENTED     (I2COLED_TIMEOUT_FF  == \
                                                        I2COLED_TIMEOUT_IMPLEMENTATION)
#define I2COLED_TIMEOUT_UDB_IMPLEMENTED    (I2COLED_TIMEOUT_UDB == \
                                                        I2COLED_TIMEOUT_IMPLEMENTATION)

#define I2COLED_TIMEOUT_FF_ENABLED         (I2COLED_TIMEOUT_ENABLED && \
                                                     I2COLED_TIMEOUT_FF_IMPLEMENTED)

#define I2COLED_TIMEOUT_UDB_ENABLED        (I2COLED_TIMEOUT_ENABLED && \
                                                     I2COLED_TIMEOUT_UDB_IMPLEMENTED)

#define I2COLED_EXTERN_I2C_INTR_HANDLER    (0u)
#define I2COLED_EXTERN_TMOUT_INTR_HANDLER  (0u)

#define I2COLED_INTERN_I2C_INTR_HANDLER    (0u == I2COLED_EXTERN_I2C_INTR_HANDLER)
#define I2COLED_INTERN_TMOUT_INTR_HANDLER  (0u == I2COLED_EXTERN_TMOUT_INTR_HANDLER)


/***************************************
*       Type defines
***************************************/

/* Structure to save registers before go to sleep */
typedef struct
{
    uint8 enableState;

#if (I2COLED_FF_IMPLEMENTED)
    uint8 xcfg;
    uint8 cfg;
    uint8 addr;
    uint8 clkDiv1;
    uint8 clkDiv2;
#else
    uint8 control;
#endif /* (I2COLED_FF_IMPLEMENTED) */

#if (I2COLED_TIMEOUT_ENABLED)
    uint16 tmoutCfg;
    uint8  tmoutIntr;
#endif /* (I2COLED_TIMEOUT_ENABLED) */

} I2COLED_BACKUP_STRUCT;


/***************************************
*        Function Prototypes
***************************************/

void I2COLED_Init(void)                            ;
void I2COLED_Enable(void)                          ;

void I2COLED_Start(void)                           ;
void I2COLED_Stop(void)                            ;

#define I2COLED_EnableInt()        CyIntEnable      (I2COLED_ISR_NUMBER)
#define I2COLED_DisableInt()       CyIntDisable     (I2COLED_ISR_NUMBER)
#define I2COLED_ClearPendingInt()  CyIntClearPending(I2COLED_ISR_NUMBER)
#define I2COLED_SetPendingInt()    CyIntSetPending  (I2COLED_ISR_NUMBER)

void I2COLED_SaveConfig(void)                      ;
void I2COLED_Sleep(void)                           ;
void I2COLED_RestoreConfig(void)                   ;
void I2COLED_Wakeup(void)                          ;
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

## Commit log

2021-06-14 BOM update
    [DTR-1_v2021-05-06_BOM.csv]
2021-06-20 Cypress PSoC Creator sources added.
    [DTR-1 v2 HW.sdf]
2023-09-19 Reset signal corrected for BS170 usage, sources update to PSoC Creator 4.4
    [DTR-1 v2 HW.sdf]

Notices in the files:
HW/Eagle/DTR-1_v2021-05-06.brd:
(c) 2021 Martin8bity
